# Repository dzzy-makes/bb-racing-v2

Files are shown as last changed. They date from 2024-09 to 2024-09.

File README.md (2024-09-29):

[Demonstration](https://youtube.com/shorts/XMrTAcSl4VY?si=B5vYV4Wz0NkW1fMc)

# Parts list

| Item | Configuration | Cost order + Shipping | Cost per unit | Units needed | Link |
|---|---|---|---|---|---|
| Square Button | 3-6V <br> 1NO 1NC 5PCS <br> Self reset | 5.59€ | 5.59€ | 2 | [Here](https://de.aliexpress.com/item/1005005791728074.html?channel=twinner) |
| Engine Start button | - | 3.75€ | 3.75€ | 1 | [Here](https://de.aliexpress.com/item/1005007038224850.html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,scm-url:1007.40050.354490.0,pvid:5076895b-e31f-49f9-b2b2-804f4f98032d,tpp_buckets:668%232846%238115%232000&pdp_npi=4%40dis%21EUR%217.49%213.75%21%21%2157.10%2128.55%21%40211b617b17275174681276900e10f4%2112000039180054877%21rec%21DE%216003558799%21X&utparam-url=scene%3ApcDetailTopMoreOtherSeller%7Cquery_from%3A) |
| Mini On/On Switch | - | 2.54€ | 0.25€ | 1 | [Here](https://de.aliexpress.com/item/32809087410.html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) |
| Linear Potentionmeter | 1K Ohm | 2.59€ | 0.26€ | 1 | [Here](https://de.aliexpress.com/item/1005006659172507.html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) |
| Round Button | 3.6-6V <br> 1NO1NC <br> Momentary | 13.01€ | 0.62€ | 12 | [Here](https://de.aliexpress.com/item/33058529397.html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) |
| Mini Buttons | - | 5.18€ (2 orders needed!) | 0.52€ | 6 | [Here](https://de.aliexpress.com/item/4000143836281.html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) |
| EC11 Rotary encoders  | 20MM Plum Handle | 2.59€ | 0.52€ | 2 | [Here](https://de.aliexpress.com/item/1005005983134515.html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) |
| Momentary Switches | - | 4.10€ | 2.05€ | 2 | [Here](https://de.aliexpress.com/item/32815002670.html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) |
| Arduino Pro Micro | Type C | 4.99€ | 2.50€ | 1 | [Here](https://de.aliexpress.com/item/1005006645661865.html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) 
| Diodes 1N4148 DO-35 | Type C | 1.29€ | 0.013€ | 32 | [Here](https://de.aliexpress.com/item/4000142272546.html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) 

**Total cost: 45.63€**

For the parts of which you don't buy in bulk, buy at least 1 extra. A part could be defective or you could break one in the process and to avoid the long waiting times.

## Tools you will need and assume you have laying around:
- Soldering Kit
- Wires
- 9 x M3xL3xD4 Threaded inserts (Knurled nuts for melting)
- 9 x M3x8 (longer should also work)

## Customization and different vendors

You can mix and match the colors of the buttons as you wish. 

If you find a cheaper price of the same part from a different vendor, go for it! Make sure to check if the parts are identical in size, otherwise you might have issues with fitting them into the faceplate.

If you decide on using **different parts** you need to adjust the diameters on the faceplate.

If you aren'ts happy with the placement of the mounting holes of the 3d printed box, I will upload a model without any mounting holes so you can drill them as you need.

# Building the button box
## Preperation

Make sure to bend the pins of the potentiometer as shown in the image, otherwise it won't work.

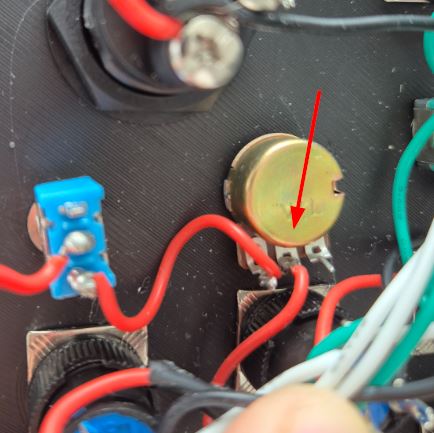
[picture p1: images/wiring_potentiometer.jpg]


## Wiring guide

For the wiring I will always highlight certain areas to help with clutter. Make sure to leave some slack on your wire since at the end you will need to solder everthing to your Arduino.

I will also add some IRL images in the beginning for reference.

### Big picture



### Wiring the LEDs

The engine start button needs it's own powersource and needs to be constantly on. Due to the way the part is designed it needs to have a power source to send a signal (if you find a better way to deal with this lmk).



### Wiring the matrix

When wiring the matrix make sure to carefully connect it as shown in the wiring schematic or you might  run into issues.

For the rows make sure that the black stripe of the diode (the small orange thingies) **faces the pin** of the button. If you wire them backwards it won't work. They diodes are **optional** but they prevent [ghosting](https://www.microsoft.com/applied-sciences/projects/anti-ghosting#:~:text=Ghosting%20is%20the%20problem%20that,to%20have%20been%20%E2%80%9Cghosted%E2%80%9D.) from happening so I recommend it.



### Wiring the rotary encoders + Engine Start



### IRL reference



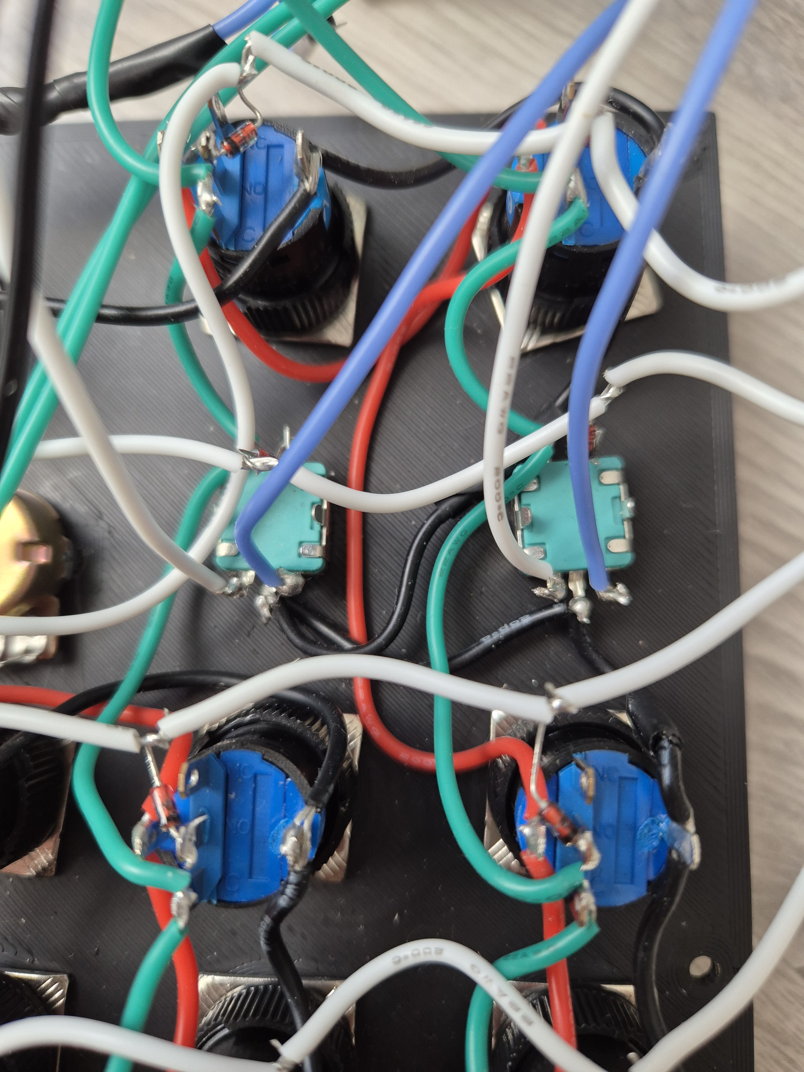
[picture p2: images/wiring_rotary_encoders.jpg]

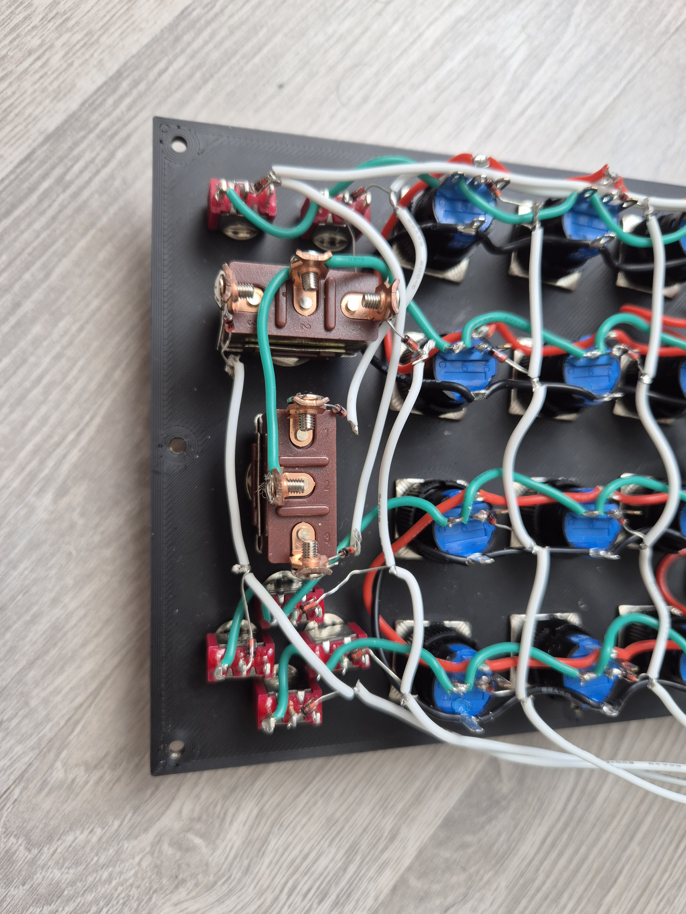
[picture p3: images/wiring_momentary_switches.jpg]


## Uploading the code

1. Download the [Arduino IDE](https://www.arduino.cc/en/software).

2. Make sure to close NZXT CAM if you have it installed since it conflicts with the uploading for some reason.

3. Download the code on the repository and unzip the contents.

4. Open th racingBB.inp file

5. Add the ZIP library in code/libraries/
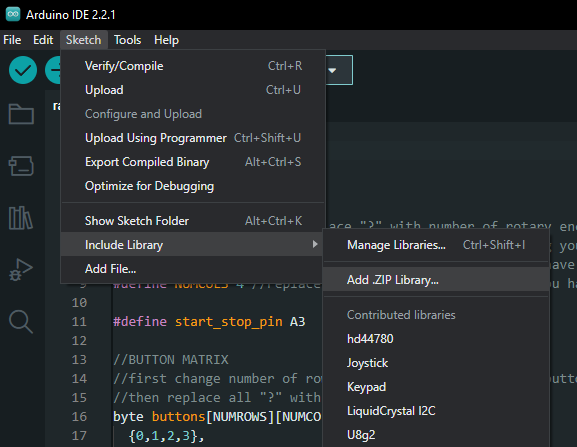
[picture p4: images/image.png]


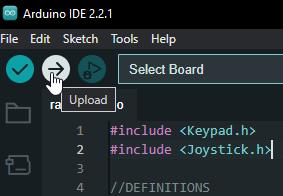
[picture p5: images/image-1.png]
6. Upload the code 

## Testing

1. Set up usb game controllers


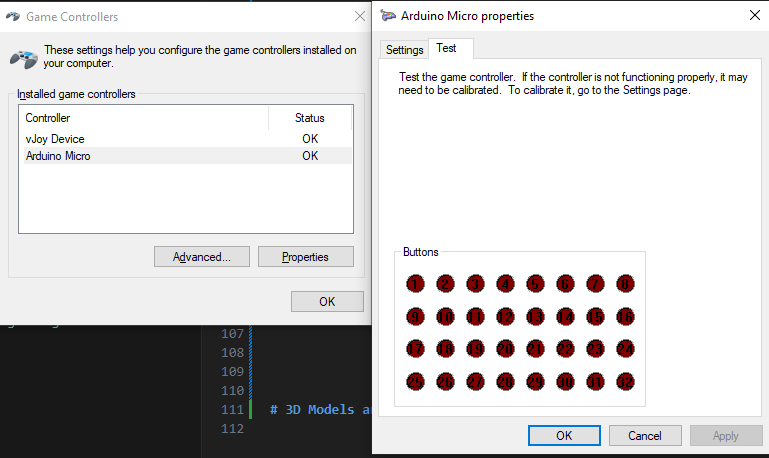
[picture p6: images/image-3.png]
2. Select "Arduino Micro" and click "Properties" 

3. Now make sure that every button gets recognized when pressed

## Troubleshooting

> When pressing a button two are getting pressed at the same time.

This usually happens when you are shorting a columns/row with another. Make sure none of them are touching.

## Mounting

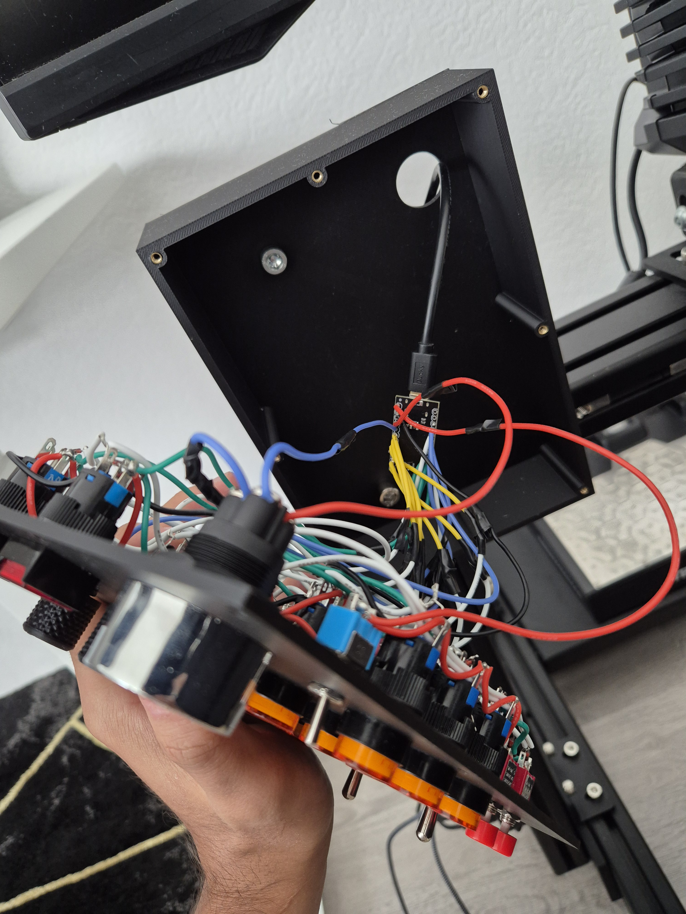
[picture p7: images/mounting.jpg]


# 3D Models and tutorials I used

https://www.youtube.com/watch?v=wkY1NsbWj5I

https://www.thingiverse.com/thing:4206617

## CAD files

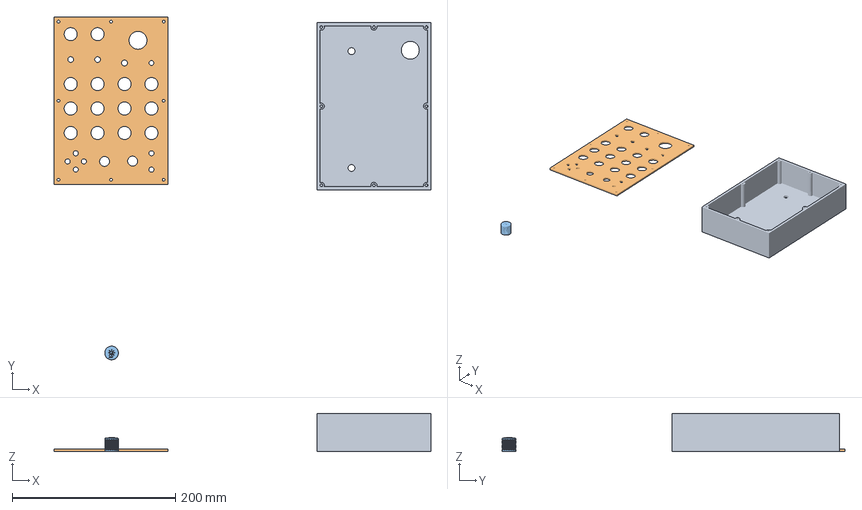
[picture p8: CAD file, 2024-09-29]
3d files/everything.3mf
462.4 x 420.3 x 47.0 mm
Case_with_mounting_holes.stl
Faceplate.stl
brightness_knob.stl

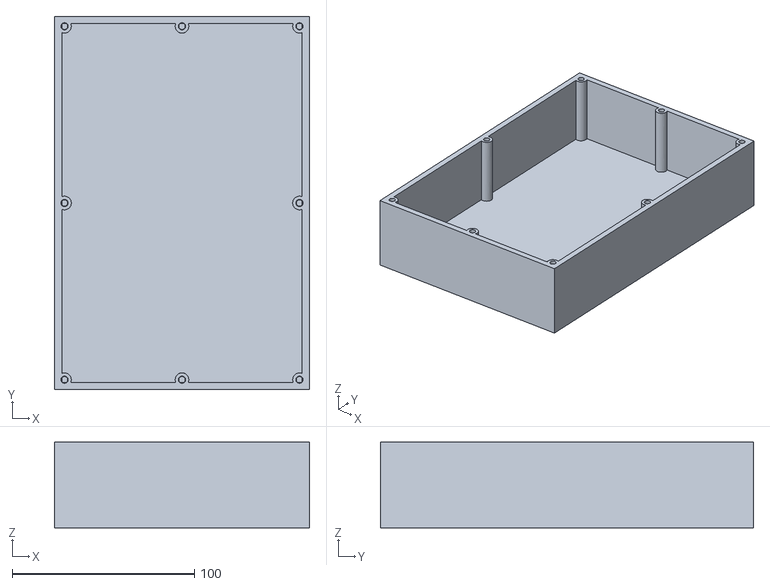
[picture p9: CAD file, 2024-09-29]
3d files/case_without_holes.stl
140.0 x 205.0 x 47.0

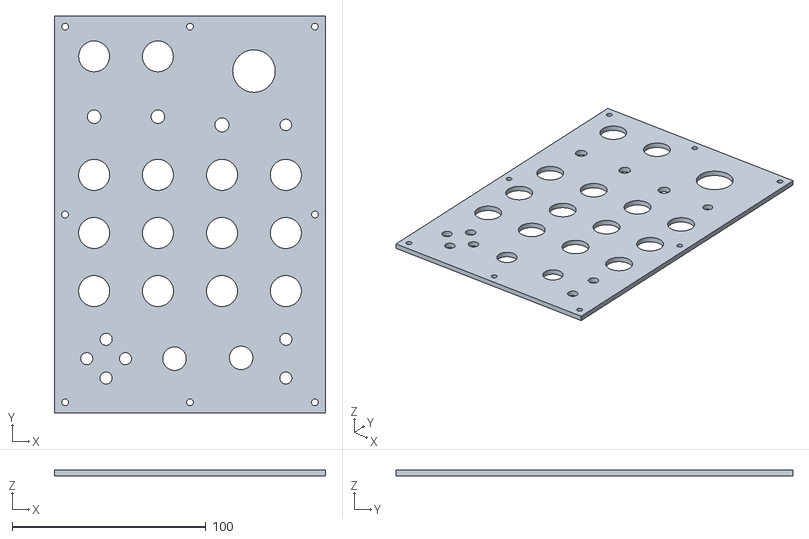
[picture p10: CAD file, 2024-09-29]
3d files/Faceplate.stl
140.0 x 205.0 x 3.00

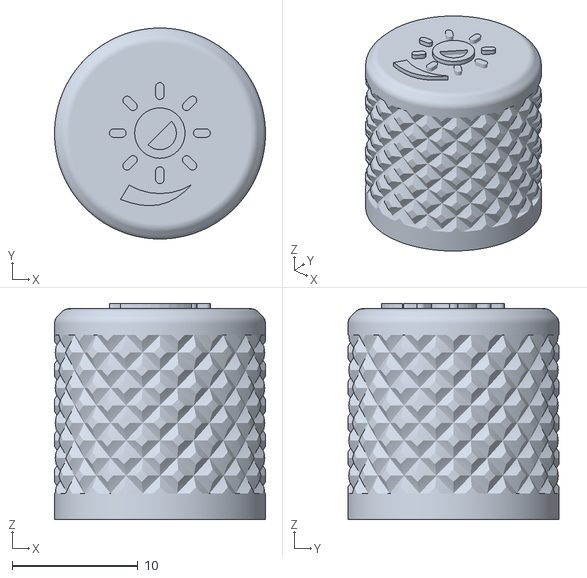
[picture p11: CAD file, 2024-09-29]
3d files/brightness_knob.stl
16.8 x 16.8 x 17.2

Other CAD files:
3d files/Case_with_mounting_holes.stl

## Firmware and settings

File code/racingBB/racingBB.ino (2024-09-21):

#include <Keypad.h>
#include <Joystick.h>

//DEFINITIONS
#define ENABLE_PULLUPS
#define NUMROTARIES 2 //replace "?" with number of rotary encoders you are using
#define NUMBUTTONS 26 //replace "?"with number of buttong you are using
#define NUMROWS 7 //replace "?" with number of rows you have
#define NUMCOLS 4 //replace "?" with number of columns you have

#define start_stop_pin A3

//BUTTON MATRIX
//first change number of rows and columns to match your button matrix, 
//then replace all "?" with numbers (starting from 0)
byte buttons[NUMROWS][NUMCOLS] = {
  {0,1,2,3},
  {4,5,6,7},
  {8,9,10,11},
  {12,13,14,15},
  {16,17,18,19},
  {20,21,22,23},
  {24,25,26,27}
};

struct rotariesdef {
  byte pin1;
  byte pin2;
  int ccwchar;
  int cwchar;
  volatile unsigned char state;
};

//ROTARY ENCODERS
//each line controls a different rotary encoder
//the first two numbers refer to the pins the encoder is connected to 
//the second two are the buttons each click of the encoder wil press 
//do NOT exceed 31 for the final button number
rotariesdef rotaries[NUMROTARIES] {
  {2,3,28,29,0}, //rotary 2
  {4,5,30,31,0}, //rotary 1
};

#define DIR_CCW 0x10
#define DIR_CW 0x20
#define R_START 0x0

#ifdef HALF_STEP
#define R_CCW_BEGIN 0x1
#define R_CW_BEGIN 0x2
#define R_START_M 0x3
#define R_CW_BEGIN_M 0x4
#define R_CCW_BEGIN_M 0x5
const unsigned char ttable[6][4] = {
  // R_START (00)
  {R_START_M,            R_CW_BEGIN,     R_CCW_BEGIN,  R_START},
  // R_CCW_BEGIN
  {R_START_M | DIR_CCW, R_START,        R_CCW_BEGIN,  R_START},
  // R_CW_BEGIN
  {R_START_M | DIR_CW,  R_CW_BEGIN,     R_START,      R_START},
  // R_START_M (11)
  {R_START_M,            R_CCW_BEGIN_M,  R_CW_BEGIN_M, R_START},
  // R_CW_BEGIN_M
  {R_START_M,            R_START_M,      R_CW_BEGIN_M, R_START | DIR_CW},
  // R_CCW_BEGIN_M
  {R_START_M,            R_CCW_BEGIN_M,  R_START_M,    R_START | DIR_CCW},
};
#else
#define R_CW_FINAL 0x1
#define R_CW_BEGIN 0x2
#define R_CW_NEXT 0x3
#define R_CCW_BEGIN 0x4
#define R_CCW_FINAL 0x5
#define R_CCW_NEXT 0x6

const unsigned char ttable[7][4] = {
  // R_START
  {R_START,    R_CW_BEGIN,  R_CCW_BEGIN, R_START},
  // R_CW_FINAL
  {R_CW_NEXT,  R_START,     R_CW_FINAL,  R_START | DIR_CW},
  // R_CW_BEGIN
  {R_CW_NEXT,  R_CW_BEGIN,  R_START,     R_START},
  // R_CW_NEXT
  {R_CW_NEXT,  R_CW_BEGIN,  R_CW_FINAL,  R_START},
  // R_CCW_BEGIN
  {R_CCW_NEXT, R_START,     R_CCW_BEGIN, R_START},
  // R_CCW_FINAL
  {R_CCW_NEXT, R_CCW_FINAL, R_START,     R_START | DIR_CCW},
  // R_CCW_NEXT
  {R_CCW_NEXT, R_CCW_FINAL, R_CCW_BEGIN, R_START},
};
#endif

//BUTTON MATRIX PART 2
byte rowPins[NUMROWS] = {10,16,14,15,A0,A1,A2}; //change "?" to the pins the rows of your button matrix are connected to
byte colPins[NUMCOLS] = {6,7,8,9}; //change "?" to the pins the rows of your button matrix are connected to

Keypad buttbx = Keypad( makeKeymap(buttons), rowPins, colPins, NUMROWS, NUMCOLS);

//JOYSTICK SETTINGS
Joystick_ Joystick(JOYSTICK_DEFAULT_REPORT_ID,
  JOYSTICK_TYPE_JOYSTICK,
  32, //number of buttons
  0, //number of hat switches
  //Set as many axis to "true" as you have potentiometers for
  false, // y axis
  false, // x axis
  false, // z axis
  false, // rx axis
  false, // ry axis
  false, // rz axis
  false, // rudder
  false, // throttle
  false, // accelerator
  false, // brake
  false); // steering wheel

const int numReadings = 20;
 
int readings[numReadings];      // the readings from the analog input
int index = 0;              // the index of the current reading
int total = 0;                  // the running total
int currentOutputLevel = 0;

//POTENTIOMETERS PART 1
//add all the axis' which are enabled above
int zAxis_ = 0;
int RxAxis_ = 0;   

               
//POTENTIOMETERS  PART 2
//Which pins are your potentiometers connected to?
// int potentiometerPin1 = ?; //Change "?" to the pin your potentiometer is connected to
// int potentiometerPin2 = ?;
const bool initAutoSendState = true;
int buttonState = 0;


void setup() {
  Joystick.begin();
  rotary_init();
  for (int thisReading = 0; thisReading < numReadings; thisReading++) {
    readings[thisReading] = 0;
  }
  pinMode(start_stop_pin, INPUT);
}

void loop() {
  buttonState = digitalRead(start_stop_pin);
 
  if (buttonState == HIGH) {
    Joystick.setButton(23, 1);
  }
  else{
    Joystick.setButton(23, 0);
  }
  CheckAllEncoders();
  CheckAllButtons();
  // CheckAllPotentiometers();
 
}

//POTENTIOMETERS PART 3
//change the details to match teh details above for each potentiometer you are using
void CheckAllPotentiometers(){
                           
  // //potentiometer 1
  // currentOutputLevel = getAverageOutput(potentiometerPin1);
  // zAxis_ = map(currentOutputLevel,0,1023,0,255);
  // Joystick.setZAxis(zAxis_); 

  // //potentiometer 2
  // currentOutputLevel = getAverageOutput(potentiometerPin2);
  // RxAxis_ = map(currentOutputLevel,0,1023,0,255);
  // Joystick.setRxAxis(RxAxis_);


}

int getAverageOutput(int pinToRead){
  index = 0;
  total = 0; 
 
  while (index < numReadings){
    readings[index] = analogRead(pinToRead);
    total = total + readings[index];
    index = index + 1;
    //delay (1);
  }
  return total / numReadings;
}


void CheckAllButtons(void) {
      if (buttbx.getKeys())
    {
       for (int i=0; i<LIST_MAX; i++)   
        {
           if ( buttbx.key[i].stateChanged )   
            {
            switch (buttbx.key[i].kstate) { 
                    case PRESSED:
                    case HOLD:
                              Joystick.setButton(buttbx.key[i].kchar, 1);
                              break;
                    case RELEASED:
                    case IDLE:
                              Joystick.setButton(buttbx.key[i].kchar, 0);
                              break;
            }
           }   
         }
     }
}


void rotary_init() {
  for (int i=0;i<NUMROTARIES;i++) {
    pinMode(rotaries[i].pin1, INPUT);
    pinMode(rotaries[i].pin2, INPUT);
    #ifdef ENABLE_PULLUPS
      digitalWrite(rotaries[i].pin1, HIGH);
      digitalWrite(rotaries[i].pin2, HIGH);
    #endif
  }
}


unsigned char rotary_process(int _i) {
  //Serial.print("Processing rotary: ");
  //Serial.println(_i);
  unsigned char pinstate = (digitalRead(rotaries[_i].pin2) << 1) | digitalRead(rotaries[_i].pin1);
  rotaries[_i].state = ttable[rotaries[_i].state & 0xf][pinstate];
  return (rotaries[_i].state & 0x30);
}

void CheckAllEncoders(void) {
  Serial.println("Checking rotaries");
  for (int i=0;i<NUMROTARIES;i++) {
    unsigned char result = rotary_process(i);
    if (result == DIR_CCW) {
      Serial.print("Rotary ");
      Serial.print(i);
      Serial.println(" <<< Going CCW");
      Joystick.setButton(rotaries[i].ccwchar, 1); delay(50); Joystick.setButton(rotaries[i].ccwchar, 0);
    };
    if (result == DIR_CW) {
      Serial.print("Rotary ");
      Serial.print(i);
      Serial.println(" >>> Going CW");
      Joystick.setButton(rotaries[i].cwchar, 1); delay(50); Joystick.setButton(rotaries[i].cwchar, 0);
    };
  }
  Serial.println("Done checking");
}

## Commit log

2024-09-21 init push
    [buttonbox_racing v22.stl]
2024-09-29 added 3d files
    [Case_with_mounting_holes.stl, Faceplate.stl, brightness_knob.stl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]
2024-09-29 more strength
    [everything.3mf]
2024-09-29 added mounting
